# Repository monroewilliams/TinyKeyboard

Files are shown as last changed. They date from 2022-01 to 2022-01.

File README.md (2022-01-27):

# README

This is a 4-key keyboard I put together using an [Adafruit NeoKey 1x4](https://www.adafruit.com/product/4980) board and a [Trinket M0](https://www.adafruit.com/product/3500).

This is intended to solve a pretty specific problem for me. I have a KVM switch on the desk in my home office that lets me switch between my employer-provided laptop and my personal machine. While I'm working, I like to play music that resides on my personal machine, but since the KVM is switched away from it I can't easily pause or skip songs. This is intented to solve that problem -- I can leave it plugged directly into the machine with the music on it and use it to control playback.

For my specific case, I've got the first three keys configured as media keys:
- Play/pause 
- Skip forward
- Skip backward

and the fourth key configured to send `F15`. On my personal machine, this is configured to invoke Siri, which allows me to use voice commands to switch albums or whatever. I don't have any volume control or mute keys set up, since I'm running through a desktop speaker setup that has a physical volume knob.

Using this as a starting point, it would of course be trivial to reconfigure the keys to anything that's useful to you, or even add some logic for chording, modality or other use cases. Have fun with it!

The LEDs are essentially doing the same thing as the sample code I lifted from the [basic example](https://github.com/adafruit/Adafruit_Seesaw/blob/master/examples/NeoKey_1x4/basic/basic.ino) included with the Adafruit seesaw library, I just tweaked the colors to be more to my liking.

There is one slightly novel thing about the startup code. In the startup() method, there's a loop that waits for the USB device to mount, cycling the LEDs in white while it does. Once the device mounts, it sets them all to green and quickly fades to black. 

If the mount doesn't happen for a full 5 seconds (which will be the case if it's only plugged into power but NOT usb), it instead does a red-to-black fade and goes into the main loop anyway. This is just so that the blinky lights can be easily demoed by plugging into a USB charger if a computer isn't available.

# HARDWARE

I built this around the Trinket M0 because I had one lying around, and I hadn't actually found a good use for it. It's cool and really tiny, but most of the projects I do just need a few more pins. Pairing it with the NeoKey (which uses I2C to communicate) works great, although it does require a little soldering since the Trinket doesn't have a STEMMA QT connector:

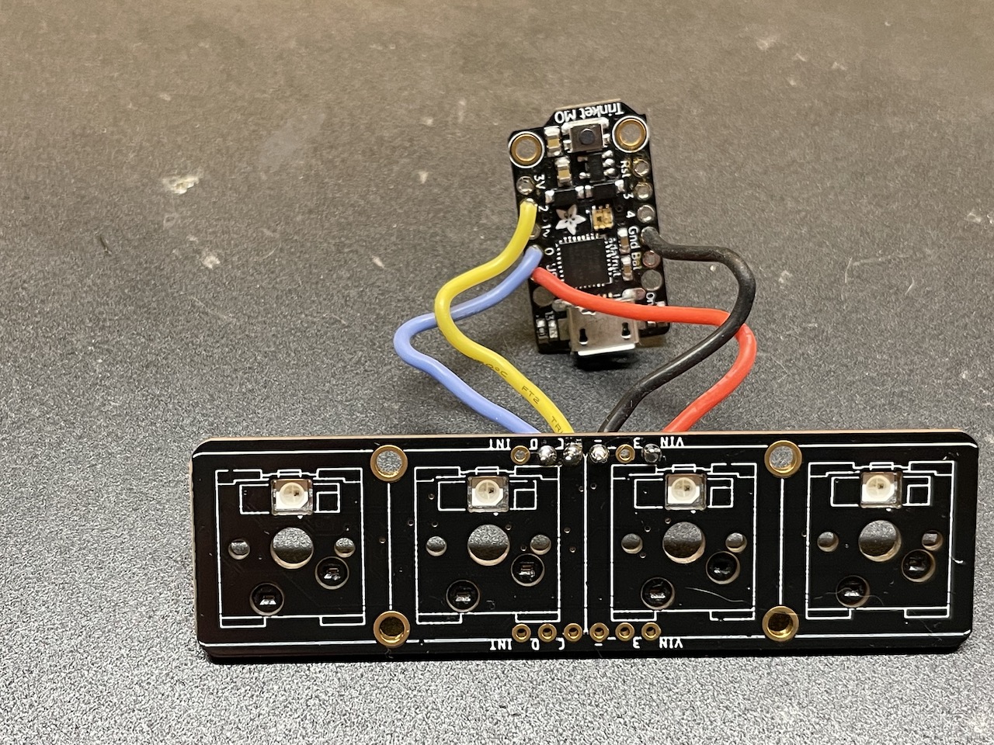
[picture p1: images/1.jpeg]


The 3D printed case was designed in OpenSCAD, and I've included the [.scad source](case/case.scad) as well as an STL file that contains both the base and the lid. 

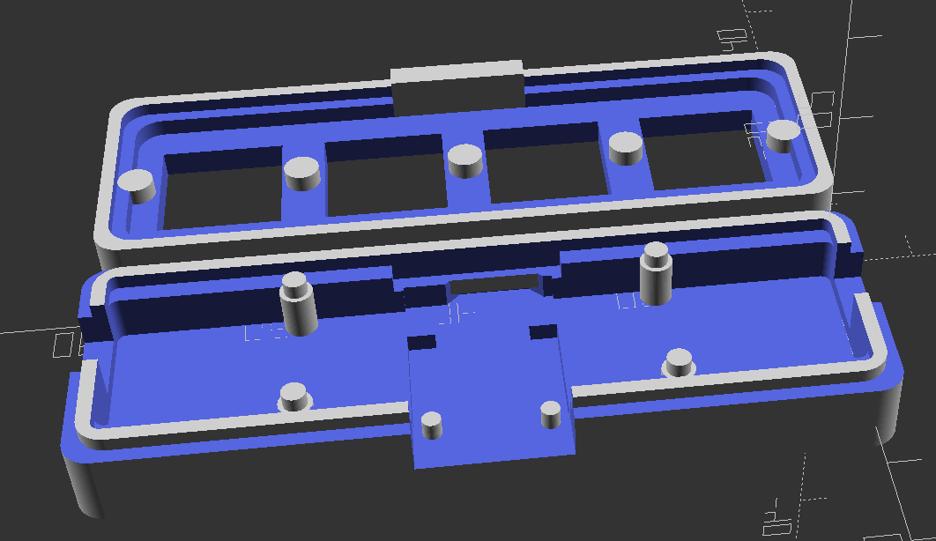
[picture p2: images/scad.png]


I printed the case in clear/natural PETG (because that's my material of choice), using Cura to slice it with 100% infill and the "Concentric" pattern for top/bottom layers (it would function just fine at 25% infill, but with clear filament the infill shows through and looks not-great, and Concentric just makes a cool pattern).

The projection on the back end of the Trinket fits into a small notch in the side of the case, and the mounting holes near the USB connector fit down over pegs that stick up from the base. I've left a 2mm deep space below the solder pads, which should be plenty of room, but if the ends of the wires you soldered on were sticking through more than that you may need to trim the excess.

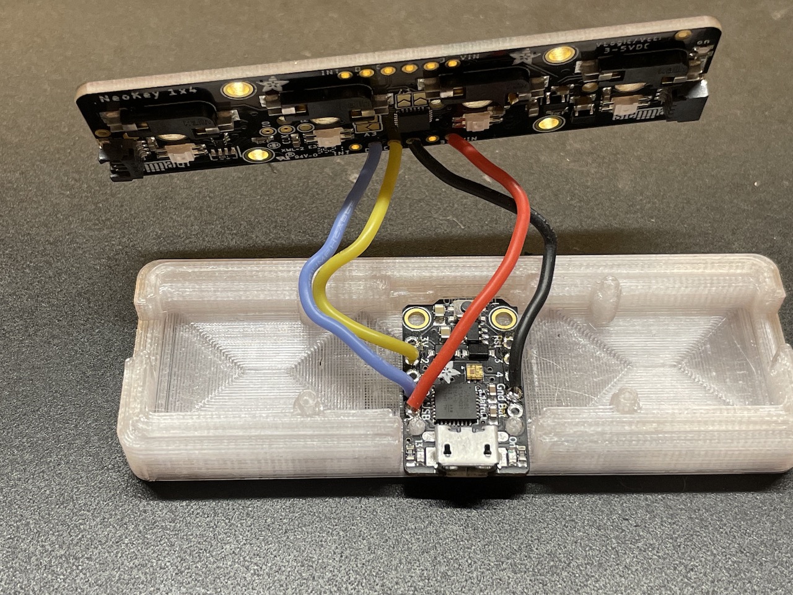
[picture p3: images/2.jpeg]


The NeoKey 1x4 board snaps down onto mounting pegs so that it's over the top of the Trinket. Bend the wires to the sides so they're out of the way as you put it in place.

The top half of the case has projections that stick down and trap both the Trinket and the NeoKey board in place. It's just a friction-fit, but I find that it holds together very well for me.

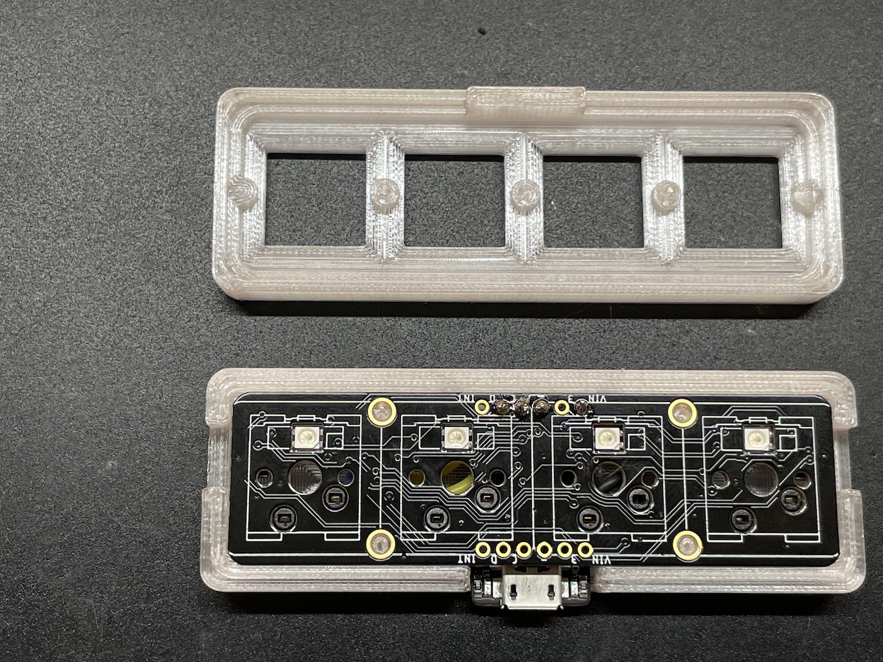
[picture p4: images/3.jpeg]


I've included cutouts in the ends of the case so that you can use the STEMMA QT plugs at either end of the NeoKey board to chain more I2C devices. I haven't done anything with these myself yet (and there's nothing in the code to talk to additional devices), so that's left as an exercise to the reader. ;) 

These cutouts are also useful for getting the case open -- I use a spudger in the cutout to gently pry one end loose, and from there it's easy to separate the top.

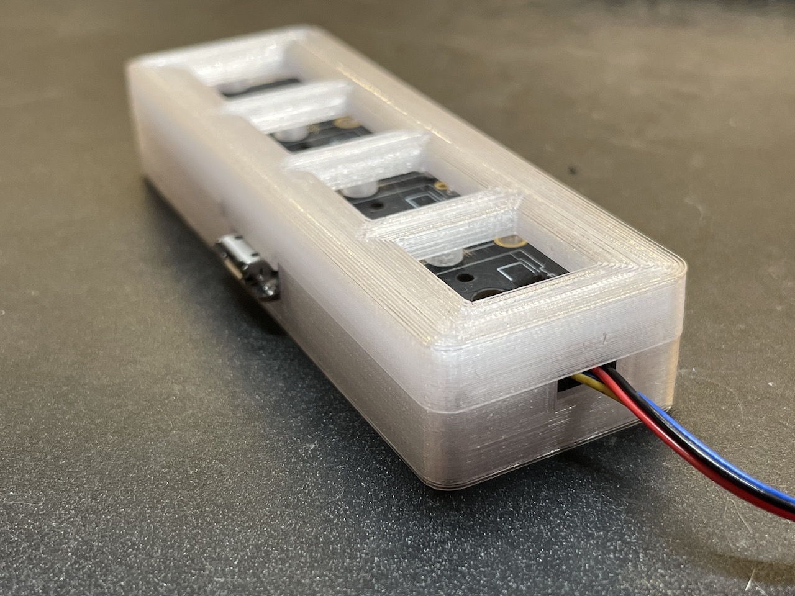
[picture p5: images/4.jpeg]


From there, just add 4 Cherry MX compatible switches and key caps and plug it in. Enjoy!

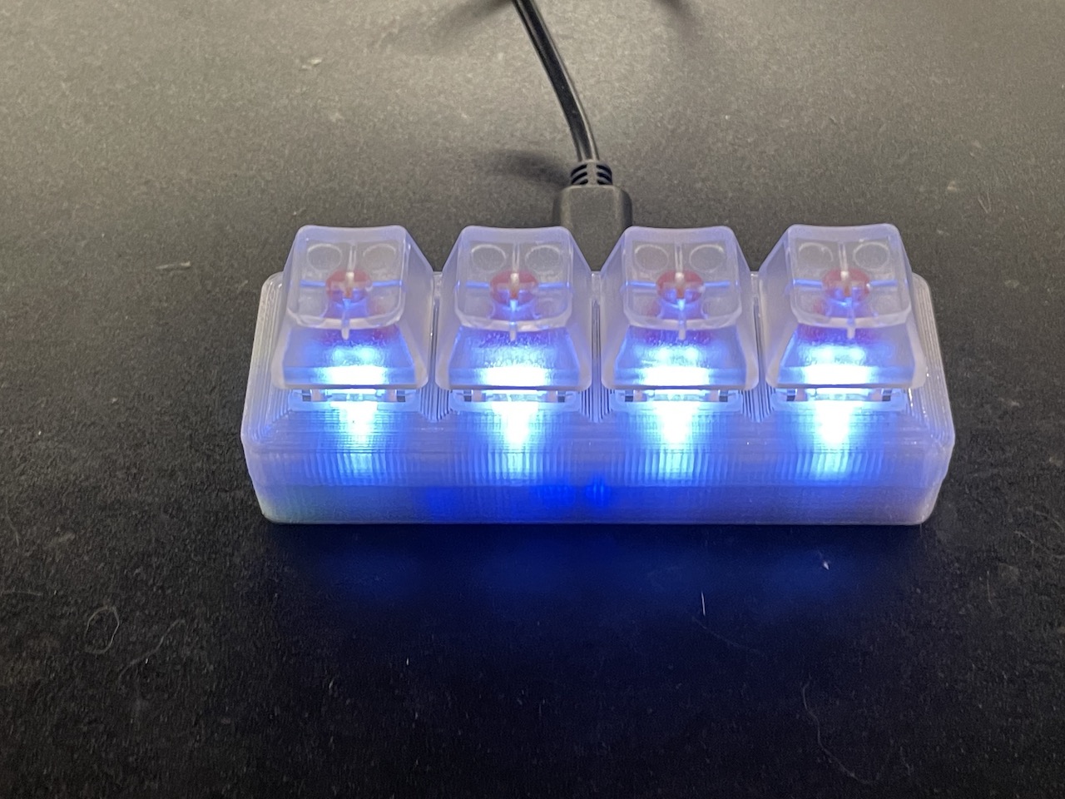
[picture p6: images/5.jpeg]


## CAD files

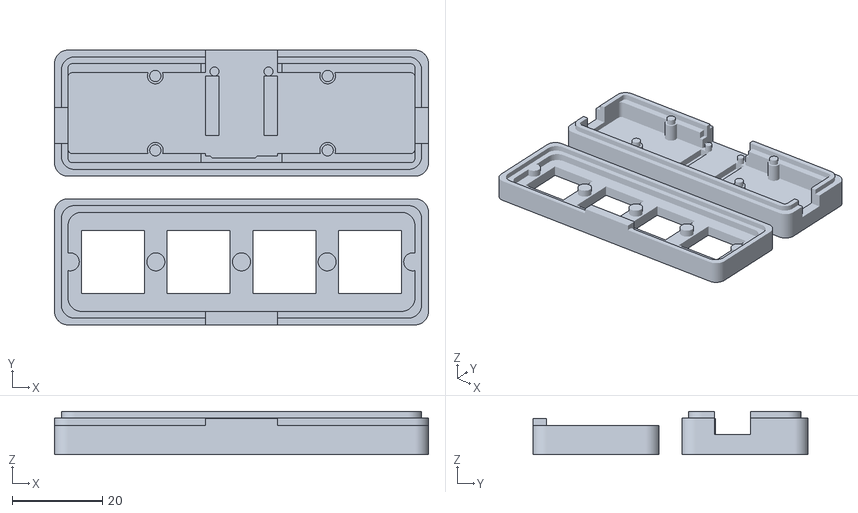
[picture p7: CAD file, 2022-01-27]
case/case.stl
83.0 x 61.0 x 9.60

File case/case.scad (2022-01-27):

neokey_length = 77;
neokey_width = 22;
neokey_spacing = 5;
neokey_height = neokey_spacing + 1.6;
interior_width = neokey_width;
interior_length = neokey_length;
interior_height = neokey_height;
wall_thickness = 3;

$fa=4;
$fs=0.1;

module rcube(x, y, z, r)
{
    translate([r, r, 0])
    linear_extrude(height = abs(z))
    offset(r)
    square([x - (r * 2), y - (r * 2)]);
}

module neokey_pins()
{
   // hole center spacing: 38.25 x 16.5
   x = 38.25;
   y = 16.5;
   mounting_hole_positions = [[-x/2,-y/2], [x/2,-y/2], [-x/2, y/2], [x/2, y/2]];
   translate([neokey_length/2, neokey_width/2])
   for(t = mounting_hole_positions) {
        translate(t) {
            translate([0, 0, -1]) {
                cylinder(h=neokey_spacing + 1, d=3.5);
                cylinder(h=neokey_height + 1, d=2.5);
            }
        }
   }
}

module neokey_cutout()
{
   difference()
   {
       union() {
             translate([0, 0, 5])
             rcube(neokey_length, neokey_width, 20, 1);
             translate([(neokey_length - 18) / 2, 0, 3])
             rcube(18, neokey_width, 20, 0);
             translate([0, (neokey_width - 18)/2])
             rcube(neokey_length, 18, 20, 1);
       }
   }
}

module trinket_pins()
{
    mounting_hole_positions = [[6, 20.25], [-6, 20.25]];
//    mounting_hole_positions = [[5.625, 4], [-5.625, 4], [6, 20], [-6, 20.25]];

    for(t = mounting_hole_positions) {
        translate(t) {
            translate([0, 0, -1]) {
                cylinder(h=2 + 1, d=2);
            }
        }
    }
}

module trinket_cutout() 
{
    
    difference() {
        union() {
            // main body
            translate([-8, 0])
            linear_extrude(20)
//            square([16, 27]);
            polygon(points = [
                [0, 1.5],
                [1.0, 1.5],
                [2.5, 0],
                [10, 0],
                [11.5, 1.5],
                [16, 1.5],
                [16, 28],
                [0, 28]
            ]);
            // cutouts for solder joints
            translate([5, 6, -2])
            linear_extrude(20)
            square([3, 13.25]);
            translate([-8, 6, -2])
            linear_extrude(20)
            square([3, 13.25]);
        }
        // Lap over the circuit board tab
        translate([-8, 0, 1])
        linear_extrude(20)
        square([16, 1]);
//        trinket_pins();
    }
}

// Trinket cutout in isolation:
if (0)
{
    translate([0, -40, 0])
    trinket_cutout();
}

// Test piece for the trinket cutout:
if (0)
{
    difference() {
        translate([-9, -1, -1])
        linear_extrude(1.95)
        square([18, 28]);
        trinket_cutout();
    }
}

// NeoKey cutout in isolation:
if(0)
{
    translate([wall_thickness, -40, 0])
    neokey_cutout();
}

// Test piece for the NeoKey cutout:
if (0)
{
    difference() {
        translate([-1, -1, -1])
        linear_extrude(neokey_height - 4)
        square([neokey_length + 2, neokey_width + 2]);
        translate([0, 0, -5])
        neokey_cutout();
    }
}

// Test piece for relative fit of both:
if (0)
{
    difference() {
        translate([-1, -1, -1])
        linear_extrude(neokey_height)
        square([neokey_length + 2, neokey_width + 2]);
        translate([0, 0, -1])
        neokey_cutout();
    }
}

module base()
{
    union()
    {
        difference() 
        {
            translate([-wall_thickness, -wall_thickness, -wall_thickness])
            difference()
            {
                // outer body
                rcube(
                    interior_length + (2 * wall_thickness), 
                    interior_width + (2 * wall_thickness),
                    neokey_height + wall_thickness,
                    wall_thickness);

                // lid cut
    //            color("red")
                translate([0, 0, neokey_height + (wall_thickness/2)])
                difference()
                {
                    rcube(
                        interior_length + (wall_thickness * 2) + 1, 
                        interior_width + (wall_thickness * 2) + 1,
                        wall_thickness,
                        wall_thickness);
                
                    translate([wall_thickness / 2, wall_thickness / 2, -wall_thickness])
                    rcube(
                        interior_length + wall_thickness, 
                        interior_width + wall_thickness,
                        wall_thickness * 2,
                        wall_thickness);
                }    
            }
        
        
            // NeoKey cut
            neokey_cutout();
            
            // Trinket cut
            translate([(neokey_length / 2), 0, 0])
            trinket_cutout();
        
            
            // Stemma connector cutouts
            translate([
                -wall_thickness - 1, 
                4 + 0.25, 
                neokey_height - (1.6 + 3) - 0.5])
            cube([5, 8, 6]);

            translate([
                interior_length - 1, 
                4 + 0.25, 
                neokey_height - (1.6 + 3) - 0.5])
            cube([5, 8, 6]);
        }
        
        // NeoKey pins
        neokey_pins();
        
        // Trinket pins
        translate([(neokey_length / 2), 0, 0])
        trinket_pins();
    }
}

module lid()
{
    // This is the height of the key switches, from the mounting board
    // to the underside of the grid.
    key_to_board_height = 5;
    key_spacing = 19;
    key_y = (neokey_width / 2);
    key_x = (neokey_length / 2) - (key_spacing * 1.5);
    key_locations = [
        [key_x + (19 * 0), key_y],
        [key_x + (19 * 1), key_y],
        [key_x + (19 * 2), key_y],
        [key_x + (19 * 3), key_y],
    ];
    holddown_x = key_x - (key_spacing * 0.5);
    board_hold_down_locations = [
        [holddown_x + (19 * 0), key_y],
        [holddown_x + (19 * 1), key_y],
        [holddown_x + (19 * 2), key_y],
        [holddown_x + (19 * 3), key_y],
        [holddown_x + (19 * 4), key_y],
    ];
    
    difference()
    {
        translate([-wall_thickness, -wall_thickness, -wall_thickness])
        difference()
        {
            rcube(
                interior_length + (wall_thickness * 2), 
                interior_width + (wall_thickness * 2),
                key_to_board_height + (wall_thickness/2),
                wall_thickness);
        
            translate([wall_thickness / 2, wall_thickness / 2, key_to_board_height])
            rcube(
                interior_length + wall_thickness, 
                interior_width + wall_thickness,
                10,
                wall_thickness);
    
            translate([wall_thickness, wall_thickness, wall_thickness])
            rcube(
                interior_length, 
                interior_width,
                10,
                wall_thickness);
        }
        
        for(t = key_locations) {
            translate(t) {
                translate([0, 0, -1]) {
                    cube([14, 14, 20], center = true);
                }
            }
        }
    }
    
    for (t = board_hold_down_locations) {
        translate(t) {
            translate([0, 0, 0]) {
                cylinder(h=key_to_board_height - wall_thickness, d=4);
            }
        }
    }
    
    // The amount that the hold-down needs to stick down from the top lip of the lower case
    trinket_stickdown_height = 3;
    
    // The stick-down to hold the trinket in place
    translate([((neokey_length / 2)) - 8, -wall_thickness, -wall_thickness])
    cube([16, wall_thickness, 5 + trinket_stickdown_height]);
}

base();

if (1)
{
    // Separate the lid from the bottom
    translate([0, -(5 + interior_width + wall_thickness * 2), 0])
    
    // Put the lid in place
//    translate([0, neokey_width, neokey_height + 2]) rotate([180, 0, 0])
    
    lid();
}

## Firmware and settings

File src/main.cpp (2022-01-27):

#include <Arduino.h>
#include "Adafruit_NeoKey_1x4.h"
#include "seesaw_neopixel.h"
#include "Adafruit_TinyUSB.h"

Adafruit_NeoKey_1x4 neokey;  

#if defined(LED_BUILTIN)
#endif

#if defined(INTERNAL_DS_DATA)
  #include <Adafruit_DotStar.h>
  Adafruit_DotStar builtin_dotstar(1, INTERNAL_DS_DATA, INTERNAL_DS_CLK, DOTSTAR_BGR);
#endif

// Report ID
enum
{
  RID_ZERO = 0,
  RID_KEYBOARD,
  RID_CONSUMER_CONTROL, // Media, volume etc ..
};

// HID report descriptor using TinyUSB's template
uint8_t const desc_hid_report[] =
{
  TUD_HID_REPORT_DESC_KEYBOARD( HID_REPORT_ID(RID_KEYBOARD) ),
  TUD_HID_REPORT_DESC_CONSUMER( HID_REPORT_ID(RID_CONSUMER_CONTROL) )
};

// USB HID object. For ESP32 these values cannot be changed after this declaration
// desc report, desc len, protocol, interval, use out endpoint
Adafruit_USBD_HID usb_hid(desc_hid_report, sizeof(desc_hid_report), HID_ITF_PROTOCOL_NONE, 2, false);

// // Output report callback for LED indicator such as Caplocks
// void hid_report_callback(uint8_t report_id, hid_report_type_t report_type, uint8_t const* buffer, uint16_t bufsize)
// {
//   (void) report_id;
//   (void) bufsize;

//   // LED indicator is output report with only 1 byte length
//   if ( report_type != HID_REPORT_TYPE_OUTPUT ) return;

//   // The LED bit map is as follows: (also defined by KEYBOARD_LED_* )
//   // Kana (4) | Compose (3) | ScrollLock (2) | CapsLock (1) | Numlock (0)
//   uint8_t ledIndicator = buffer[0];

//   // turn on LED if capslock is set
//   // digitalWrite(LED_BUILTIN, ledIndicator & KEYBOARD_LED_CAPSLOCK);

// #ifdef PIN_NEOPIXEL
//   pixels.fill(ledIndicator & KEYBOARD_LED_CAPSLOCK ? 0xff0000 : 0x000000);
//   pixels.show();
// #endif
// }

void setup(void) 
{  
#if defined(LED_BUILTIN)
  digitalWrite(LED_BUILTIN, HIGH);
#endif

#if defined(INTERNAL_DS_DATA)
  builtin_dotstar.setPixelColor(0, 0x0000FF);
  builtin_dotstar.show();
#endif

  // This allows us to use the "1200 baud open/close" trick to put the device into firmware upload mode.
  Serial.begin(9600);
  // delay(3000);

  // Serial.println("Starting");

  // while (! Serial) delay(1);

  // TinyUSB Setup
  USBDevice.setProductDescriptor("TinyKeyboard");
  // USBDevice.setSerialDescriptor("TinyKeyboard");
  // Serial.setStringDescriptor("TK");
  usb_hid.setStringDescriptor("TinyKeyboard");
  usb_hid.begin();

  // Set up output report (on control endpoint) for Capslock indicator
  // usb_hid.setReportCallback(NULL, hid_report_callback);

  // wait until device mounted
  // while( !USBDevice.mounted() ) delay(1);

  if (!neokey.begin(0x30)) {     // begin with I2C address, default is 0x30
    // Serial.println("Could not start NeoKey, check wiring?");
  } else {
    // Serial.println("NeoKey started!");
  }

  unsigned long start_time = millis();
  do {
    // Pulse all the LEDs on to show we're working
    for (uint16_t i=0; i<neokey.pixels.numPixels(); i++) {
      neokey.pixels.setPixelColor(i, 0x808080); // make each LED white
      neokey.pixels.show();
      delay(50);
    }

    for (uint16_t i=0; i<neokey.pixels.numPixels(); i++) {
      neokey.pixels.setPixelColor(i, 0x000000);
      neokey.pixels.show();
      delay(50);
    }

    if (millis() - start_time > 1000 * 5) {
      // We've waited over 5 seconds for USB to init, we're probably only plugged into power.
      // Continue so we can at least demo the blinkenlights.
      break;
    }
  } while(!USBDevice.mounted());

  for (int32_t c=0xff; c>= 0; c--) {
    uint32_t color = c << (USBDevice.mounted()?8:16);
    for (uint16_t i=0; i<neokey.pixels.numPixels(); i++) {
      neokey.pixels.setPixelColor(i, color); // All LEDs fade from the same color
    }
    neokey.pixels.show();
#if defined(INTERNAL_DS_DATA)
    builtin_dotstar.setPixelColor(0, color);
    builtin_dotstar.show();
#endif
    delay(1);
  }

#if defined(LED_BUILTIN)
  digitalWrite(LED_BUILTIN, LOW);
#endif
}

// button bits convenience
#define button(num) (1 << num)

void loop()
{
  const int loop_hz = 30;
  const int loop_target_time = 1000000 / loop_hz;
  unsigned long loop_start_time = micros();
  static uint8_t last_buttons = 0;
  uint8_t buttons = neokey.read();
  uint8_t buttons_changed = last_buttons ^ buttons;

  // Wake up on any button press
  if ((buttons_changed != 0) && TinyUSBDevice.suspended()) 
  {
    // Wake up host if we are in suspend mode
    // and REMOTE_WAKEUP feature is enabled by host
    TinyUSBDevice.remoteWakeup();
  }

  // Check each button, if pressed, light the matching neopixel
  if (buttons_changed & button(0))
  {
    if (buttons & button(0)) {
      // Serial.println("Button A");
      usb_hid.sendReport16(RID_CONSUMER_CONTROL, HID_USAGE_CONSUMER_PLAY_PAUSE);
      neokey.pixels.setPixelColor(0, 0xFF0000); // red
    } else {
      usb_hid.sendReport16(RID_CONSUMER_CONTROL, 0);
      neokey.pixels.setPixelColor(0, 0);
    }
  }

  if (buttons_changed & button(1))
  {
    if (buttons & button(1)) {
      // Serial.println("Button B");
      usb_hid.sendReport16(RID_CONSUMER_CONTROL, HID_USAGE_CONSUMER_SCAN_PREVIOUS);
      neokey.pixels.setPixelColor(1, 0x00FF00); // green
    } else {
      usb_hid.sendReport16(RID_CONSUMER_CONTROL, 0);
      neokey.pixels.setPixelColor(1, 0);
    }
  }

  if (buttons_changed & button(2))
  {
    if (buttons & button(2)) {
      // Serial.println("Button C");
      usb_hid.sendReport16(RID_CONSUMER_CONTROL, HID_USAGE_CONSUMER_SCAN_NEXT);
      neokey.pixels.setPixelColor(2, 0x0000FF); // blue
    } else {
      usb_hid.sendReport16(RID_CONSUMER_CONTROL, 0);
      neokey.pixels.setPixelColor(2, 0);
    }
  }

  if (buttons_changed & button(3))
  {
    if (buttons & button(3)) {
      // Serial.println("Button D");
      uint8_t keycode[6] = { 0 };
      keycode[0] = HID_KEY_F15;
      usb_hid.keyboardReport(RID_KEYBOARD, 0, keycode);
      neokey.pixels.setPixelColor(3, 0xFFFFFF); // white
    } else {
      usb_hid.keyboardRelease(RID_KEYBOARD);
      neokey.pixels.setPixelColor(3, 0);
    }  
  }

  last_buttons = buttons;

  neokey.pixels.show();

  unsigned long loop_time = micros() - loop_start_time;
  if (loop_time < loop_target_time)
  {
    delayMicroseconds(loop_target_time - loop_time);
  }
}
